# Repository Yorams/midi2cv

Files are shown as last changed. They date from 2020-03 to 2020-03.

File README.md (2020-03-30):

# midi2cv

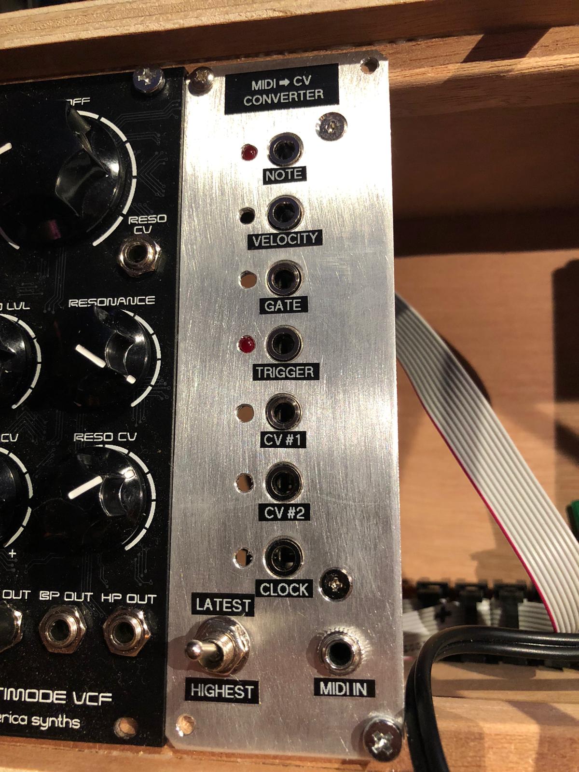
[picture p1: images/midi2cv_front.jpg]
midi2cv
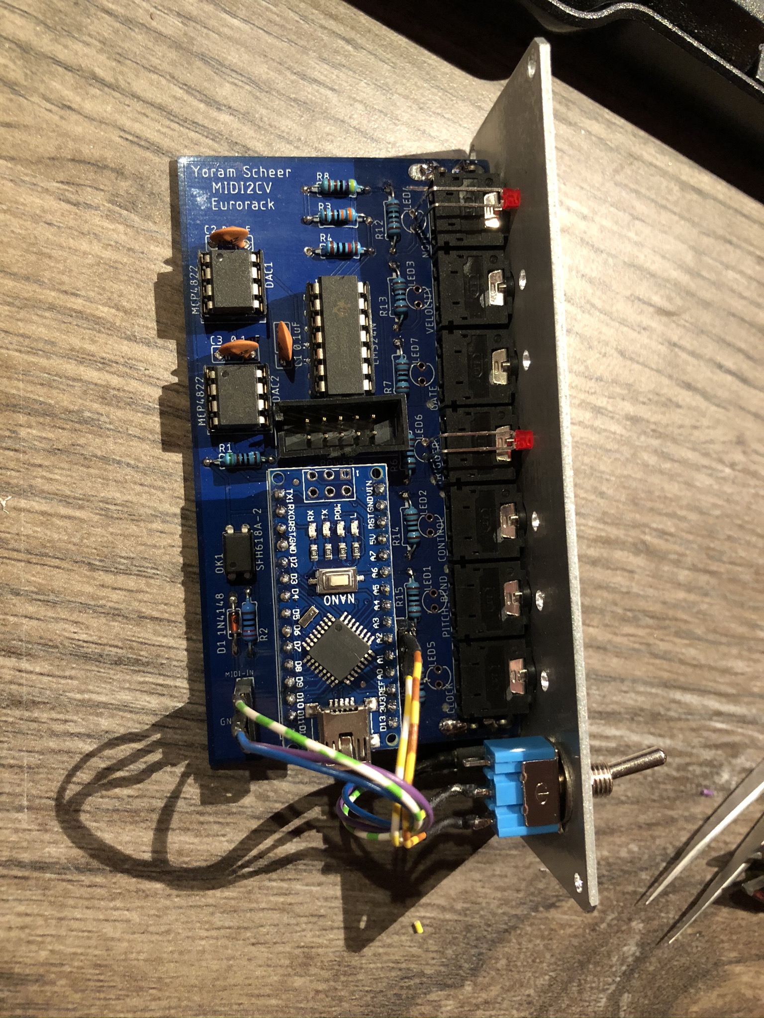
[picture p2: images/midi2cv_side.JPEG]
midi2cv
 

I forked this repository from elkayem, original found here: https://github.com/elkayem/midi2cv. I wanted to make an PCB from this schematic and needed to ajust a couple parts to match the right footprint on the PCB. 

The MIDI to CV converter includes the following outputs:

* Note CV output (88 keys, 1V/octave) using a 12-bit DAC
* Note priority (highest note, lowest note, or last note) selectable with jumper or 3-way switch
* Velocity CV output (0 to 4V)
* 2x Control Change CV outout (0 to 4V) (i changed the pitch bend to CC2 for 2 control channels)
* Trigger output (5V, 20 msec pulse for each new key played)
* Gate output (5V when any key depressed)
* Clock output (1 clock per quarter note, 20 msec 5V pulses)

## Parts
* Arduino Nano
* Optocoupler (I used a Vishay SFH618A, but there are plenty of alternatives out there)
* 2x MCP4822 12-bit DACs
* LM324N Quad Op Amp 
* Diode (e.g., 1N917)
* 220, 500, 3x1K, 7.7K (3K+4.7K), 10K Ohm resistors
* 3x 0.1 uF ceramic capacitors
* 3,5mm jack panel mount for MIDI over TRS
* 7x 3,5mm jack PCB mount Horizontal (farnell code: 2518188)
* 3-pin header and jumper *or* 3-way switch
* 3-pin header to connect MIDI-In

The Arduino code uses the standard MIDI and SPI libraries, which can be found in the Arduino Library Manager. 

The schematic is illustrated at the bottom of this page (Eagle file included).  Input power (VIN) is 9-12V.  This is required for the Note CV op amp, used for the 0-7.3V note output.  1% metal film resistors are recommended for the 7.7K and 10K resistors, for a constant op-amp gain that does not change with temperature.  Note that 7.7K is not a standard resistor value.  I used a 3K and a 4.7K resistor in series, which are much more common values.  If precise tuning is desired, a trim pot can be added *or* the constant NOTE_SF can be adjusted in the code.  I opted for the latter.

Note priority is selected using a jumper attached to the three-pin header labelled NP_SEL in the schematic.  This header connects to the Arduino pins A0 and A2, with the center pin attached to ground.  Alternatively, a 3-way switch can be attached to this header. 

The note priority options and jumper configuration are as follows:
* **Highest Note:** When multiple notes are sounded simultaneously, the highest note being held will be sounded.  When the highest note is released, the next highest note will be played, and so on.  Remove the NP_SEL jumper to select this configuration.
* **Lowest Note:** Analagous to highest note, except the lowest note being held will be sounded. Connect the NP_SEL jumper to the A0 pin and center pin (ground) to select this configuration. 
* **Last Note:** The most recent note played will be sounded.  When that note is released, the next most recent note still being held will be sounded.  Connect the NP_SEL jumper to the A2 pin and center pin (ground) to select this configuration. 

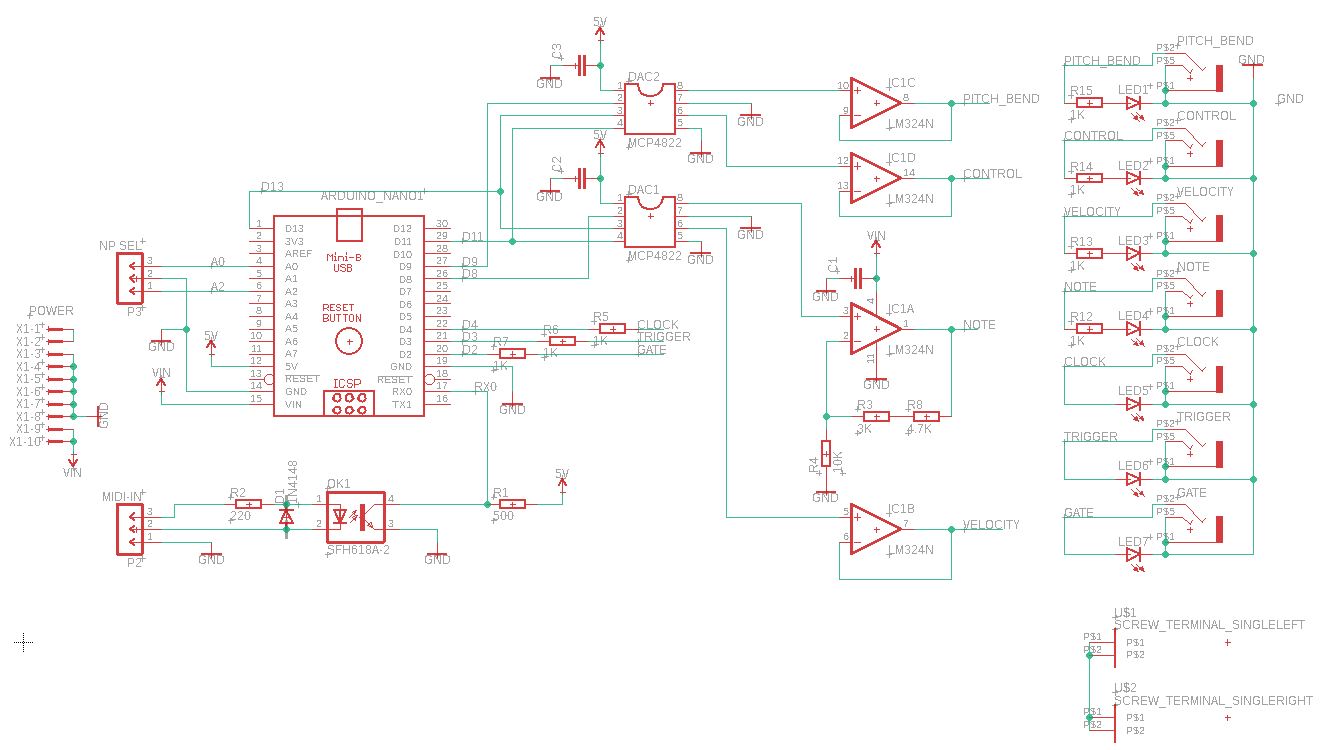
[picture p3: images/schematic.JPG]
schematic


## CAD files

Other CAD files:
frontpanel holes.dwg

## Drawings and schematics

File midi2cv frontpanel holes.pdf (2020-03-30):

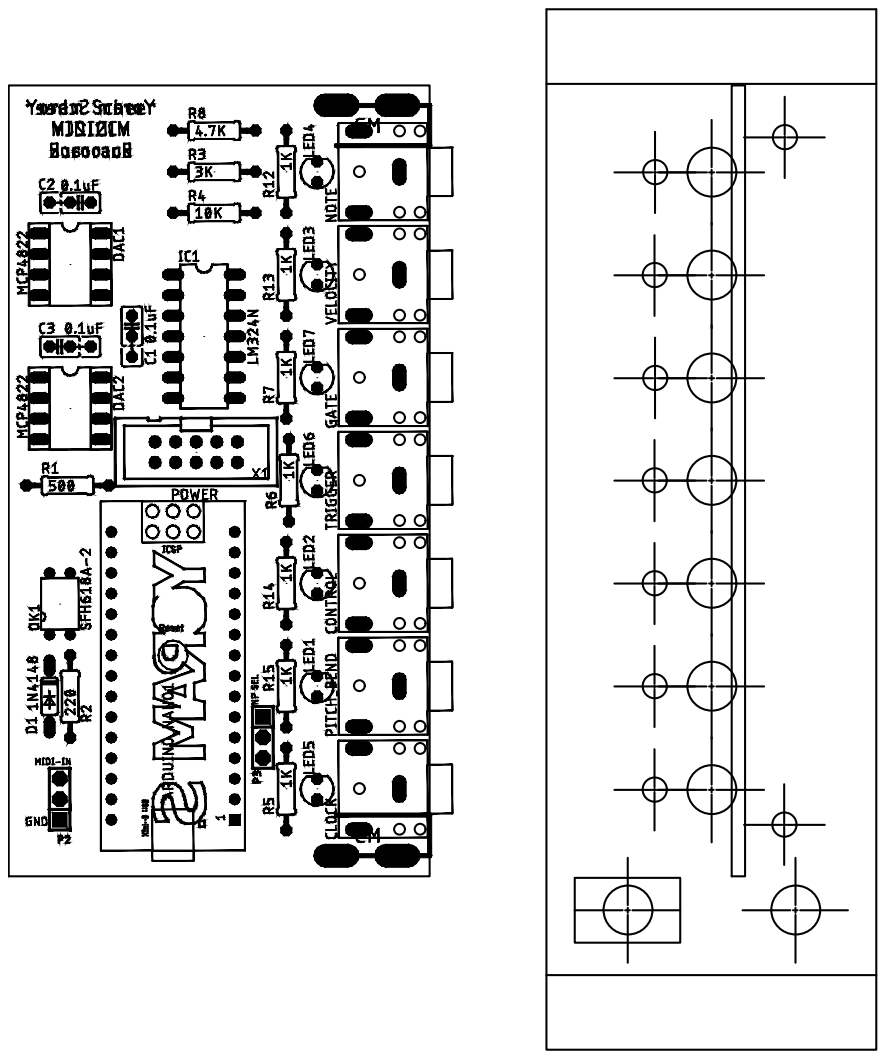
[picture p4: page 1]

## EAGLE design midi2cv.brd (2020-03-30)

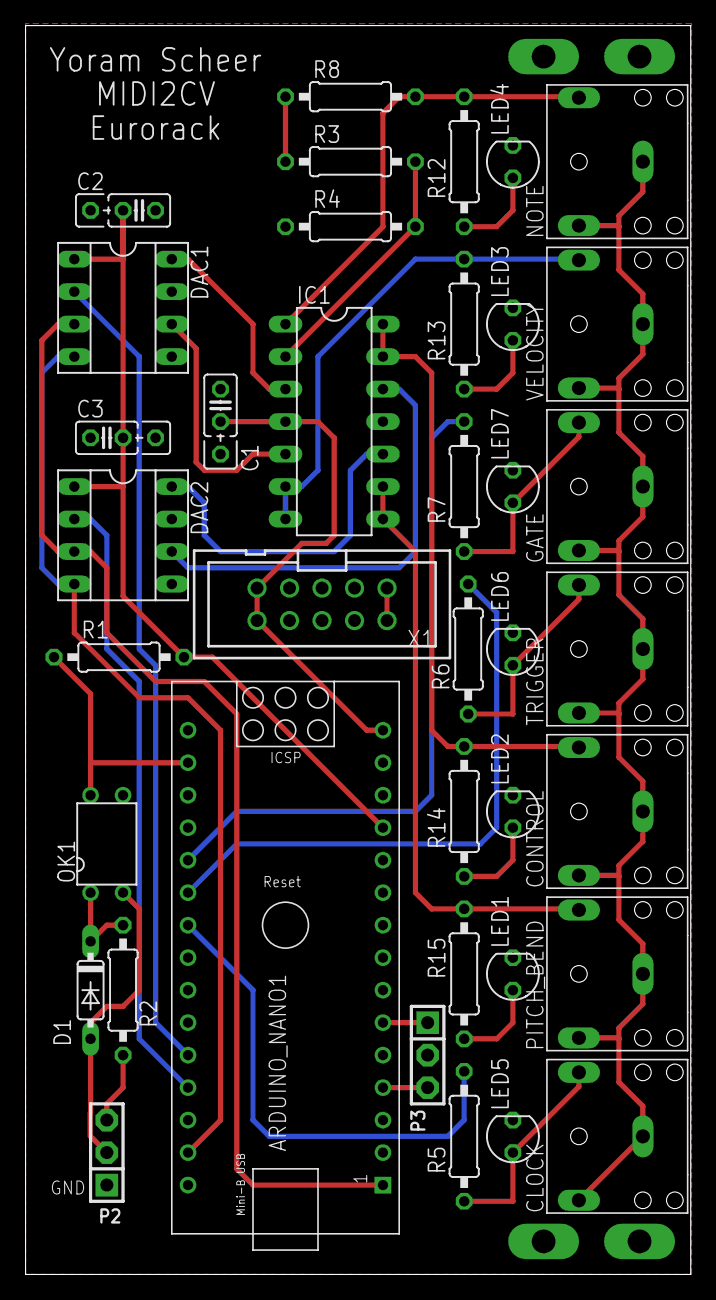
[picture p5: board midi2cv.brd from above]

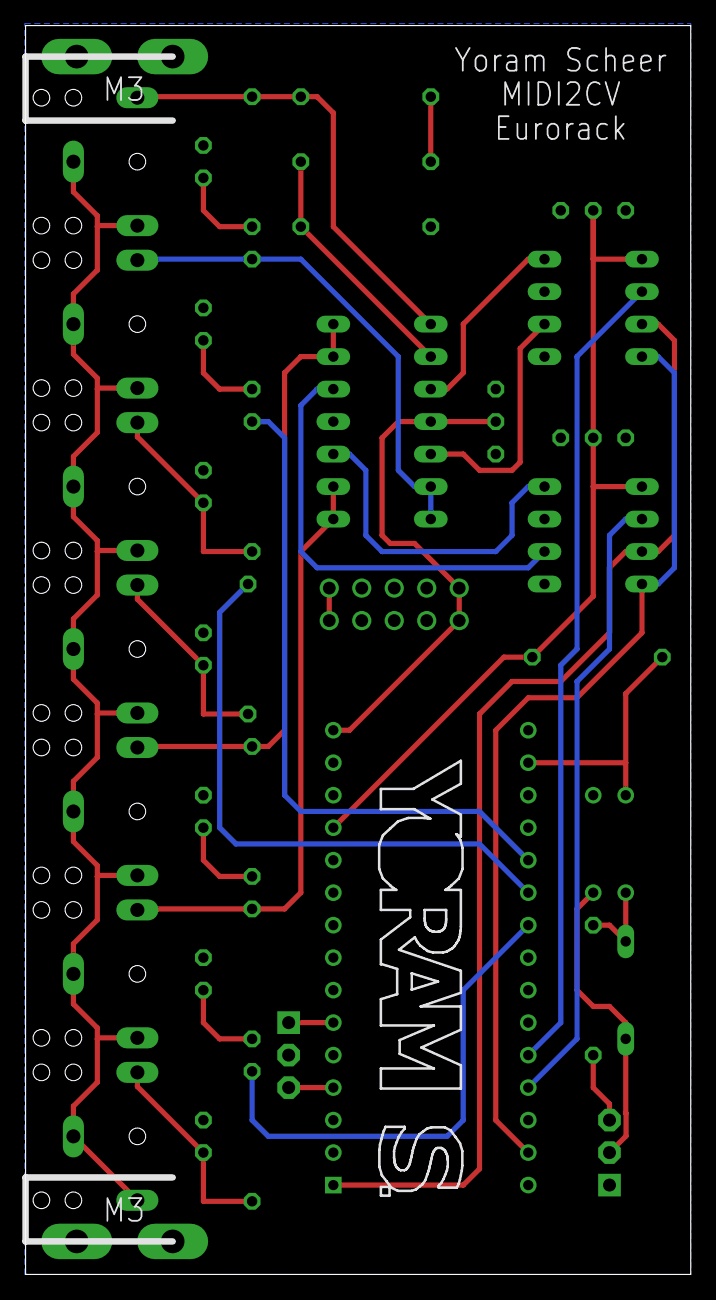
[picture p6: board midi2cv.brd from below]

Board: 2 copper layers, 52.0 x 97.6 mm, 41 parts (2 on the bottom side), 34 nets.

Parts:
ARDUINO_NANO1: ARDUINO_NANO
C1, C2, C3: 0.1uF; C025_050-025X075
CLOCK: 3.5_JACK_HORIZONTAL
CONTROL: 3.5_JACK_HORIZONTAL
D1: 1N4148; DO35-7
DAC1, DAC2: MCP4822; SOCKET-08
DRILEGEND: DRILEGEND
GATE: 3.5_JACK_HORIZONTAL
IC1: LM324N; DIL14
LED1, LED2, LED3, LED4, LED5, LED6, LED7: LED3MM
NOTE: 3.5_JACK_HORIZONTAL
OK1: SFH618A-2; DIP4
P2: MIDI-IN; SIP-100-03-40
P3: NP SEL; SIP-100-03-40
PITCH_BEND: 3.5_JACK_HORIZONTAL
R1: 500; 0207/10
R2: 220; 0207/10
R3: 3K; 0207/10
R4: 10K; 0207/10
R5, R6, R7, R12, R13, R14, R15: 1K; 0207/10
R8: 4.7K; 0207/10
TRIGGER: 3.5_JACK_HORIZONTAL
U$1: SCREW_TERMINAL_SINGLELEFT; SCREW_TERM_SINGLE_LEFT
U$2: SCREW_TERMINAL_SINGLERIGHT; SCREW_TERM_SINGLE_RIGHT
VELOCITY: 3.5_JACK_HORIZONTAL
X1: POWER; PAK100/2500-10

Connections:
5V: ARDUINO_NANO1.12, C2.2, C3.2, DAC1.1, DAC2.1, R1.2
A0: ARDUINO_NANO1.4, P3.3
A2: ARDUINO_NANO1.6, P3.1
CLOCK: CLOCK.P$2, LED5.A, R5.2
CONTROL: CONTROL.P$2, IC1.13, IC1.14, R14.1
D2: ARDUINO_NANO1.20, R7.1
D3: ARDUINO_NANO1.21, R6.1
D4: ARDUINO_NANO1.22, R5.1
D8: ARDUINO_NANO1.26, DAC1.2
D9: ARDUINO_NANO1.27, DAC2.2
D11: ARDUINO_NANO1.29, DAC1.4, DAC2.4
D13: ARDUINO_NANO1.1, DAC1.3, DAC2.3
GATE: GATE.P$2, LED7.A, R7.2
GND: ARDUINO_NANO1.14, ARDUINO_NANO1.19, C1.1, C2.1, C3.1, CLOCK.P$1, CLOCK.P$5, CONTROL.P$1, CONTROL.P$5, DAC1.5, DAC1.7, DAC2.5, DAC2.7, GATE.P$1, GATE.P$5, IC1.11, LED1.K, LED2.K, LED3.K, LED4.K, LED5.K, LED6.K, LED7.K, NOTE.P$1, NOTE.P$5, OK1.3, P2.1, P3.2, PITCH_BEND.P$1, PITCH_BEND.P$5, R4.1, TRIGGER.P$1, TRIGGER.P$5, U$1.P$1, U$1.P$2, U$2.P$1, U$2.P$2, VELOCITY.P$1, VELOCITY.P$5, X1.3, X1.4, X1.5, X1.6, X1.7, X1.8
unnamed: D1.C, OK1.1, R2.2
unnamed: D1.A, OK1.2, P2.2
unnamed: P2.3, R2.1
unnamed: DAC1.8, IC1.3
unnamed: R3.2, R8.1
unnamed: IC1.2, R3.1, R4.2
unnamed: DAC1.6, IC1.5
unnamed: DAC2.8, IC1.10
unnamed: DAC2.6, IC1.12
unnamed: X1.1, X1.2
unnamed: LED4.A, R12.2
unnamed: LED3.A, R13.2
unnamed: LED2.A, R14.2
unnamed: LED1.A, R15.2
NOTE: IC1.1, NOTE.P$2, R8.2, R12.1
PITCH_BEND: IC1.8, IC1.9, PITCH_BEND.P$2, R15.1
RX0: ARDUINO_NANO1.17, OK1.4, R1.1
TRIGGER: LED6.A, R6.2, TRIGGER.P$2
VELOCITY: IC1.6, IC1.7, R13.1, VELOCITY.P$2
VIN: ARDUINO_NANO1.15, C1.2, IC1.4, X1.9, X1.10

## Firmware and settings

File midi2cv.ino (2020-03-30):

/* 
 *    MIDI2CV 
 *    Copyright (C) 2017  Larry McGovern
 *  
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
 *    This program is distributed in the hope that it will be useful,
 *    but WITHOUT ANY WARRANTY; without even the implied warranty of
 *    MERCHANTABILITY or FITNESS FOR A PARTICULAR PURPOSE.  See the
 *    GNU General Public License <http://www.gnu.org/licenses/> for more details.
 */
 
#include <MIDI.h>
#include <SPI.h>

// Note priority is set by pins A0 and A2
// Highest note priority: A0 and A2 high (open)
// Lowest note priority:  A0 low (ground), A2 high (open)
// Last note priority:    A2 low (ground)
 
#define NP_SEL1 A0  // Note priority is set by pins A0 and A2
#define NP_SEL2 A2  

#define GATE  2
#define TRIG  3
#define CLOCK 4
#define DAC1  8 
#define DAC2  9

MIDI_CREATE_DEFAULT_INSTANCE();

void setup()
{
 pinMode(NP_SEL1, INPUT_PULLUP);
 pinMode(NP_SEL2, INPUT_PULLUP);
 
 pinMode(GATE, OUTPUT);
 pinMode(TRIG, OUTPUT);
 pinMode(CLOCK, OUTPUT);
 pinMode(DAC1, OUTPUT);
 pinMode(DAC2, OUTPUT);
 digitalWrite(GATE,LOW);
 digitalWrite(TRIG,LOW);
 digitalWrite(CLOCK,LOW);
 digitalWrite(DAC1,HIGH);
 digitalWrite(DAC2,HIGH);
 

 SPI.begin();

 MIDI.begin(MIDI_CHANNEL_OMNI);

 // Set initial pitch bend voltage to 0.5V (mid point).  With Gain = 1X, this is 1023
 // Other DAC outputs will come up as 0V, so don't need to be initialized
 setVoltage(DAC2, 0, 0, 1023);  
}

bool notes[88] = {0}; 
int8_t noteOrder[20] = {0}, orderIndx = {0};
unsigned long trigTimer = 0;

void loop()
{
  int type, noteMsg, velocity, channel, d1, d2;
  static unsigned long clock_timer=0, clock_timeout=0;
  static unsigned int clock_count=0;
  bool S1, S2;

  if ((trigTimer > 0) && (millis() - trigTimer > 20)) { 
    digitalWrite(TRIG,LOW); // Set trigger low after 20 msec 
    trigTimer = 0;  
  }

  if ((clock_timer > 0) && (millis() - clock_timer > 20)) { 
    digitalWrite(CLOCK,LOW); // Set clock pulse low after 20 msec 
    clock_timer = 0;  
  }
  
  if (MIDI.read()) {                    
    byte type = MIDI.getType();
    switch (type) {
      case midi::NoteOn: 
      case midi::NoteOff:
        noteMsg = MIDI.getData1() - 21; // A0 = 21, Top Note = 108
        channel = MIDI.getChannel();
        
        if ((noteMsg < 0) || (noteMsg > 87)) break; // Only 88 notes of keyboard are supported

        if (type == midi::NoteOn) velocity = MIDI.getData2();
        else velocity  = 0;  

        if (velocity == 0)  {
          notes[noteMsg] = false;
        }
        else {
          notes[noteMsg] = true;
          // velocity range from 0 to 4095 mV  Left shift d2 by 5 to scale from 0 to 4095, 
          // and choose gain = 2X
          setVoltage(DAC1, 1, 1, velocity<<5);  // DAC1, channel 1, gain = 2X
        }

        // Pins NP_SEL1 and NP_SEL2 indictate note priority
        S1 = digitalRead(NP_SEL1);
        S2 = digitalRead(NP_SEL2);

        if (S1 && S2) { // Highest note priority
          commandTopNote();
        }
        else if (!S1 && S2) { // Lowest note priority
          commandBottomNote();
        }
        else { // Last note priority
           if (notes[noteMsg]) {  // If note is on and using last note priority, add to ordered list
            orderIndx = (orderIndx+1) % 20;
            noteOrder[orderIndx] = noteMsg;                 
          }
          commandLastNote();         
        }
        break;
        
      case midi::PitchBend:
        d1 = MIDI.getData1();
        d2 = MIDI.getData2(); // d2 from 0 to 127, mid point = 64

        // Pitch bend output from 0 to 1023 mV.  Left shift d2 by 4 to scale from 0 to 2047.
        // With DAC gain = 1X, this will yield a range from 0 to 1023 mV.  
        //setVoltage(DAC2, 0, 0, d2<<4);  // DAC2, channel 0, gain = 1X
        
        break;

      case midi::ControlChange: 
        d1 = MIDI.getData1();
        d2 = MIDI.getData2(); // From 0 to 127

        // CC range from 0 to 4095 mV  Left shift d2 by 5 to scale from 0 to 4095, 
        // and choose gain = 2X
        
        if(d1 == 1){
          setVoltage(DAC2, 1, 1, d2<<5);  // DAC2, channel 1, gain = 2X
        }
        if(d1 == 2){
          setVoltage(DAC2, 0, 1, d2<<5);  // DAC2, channel 0, gain = 1X
        }
        
        break;
        
      case midi::Clock:
        if (millis() > clock_timeout + 300) clock_count = 0; // Prevents Clock from starting in between quarter notes after clock is restarted!
        clock_timeout = millis();
        
        if (clock_count == 0) {
          digitalWrite(CLOCK,HIGH); // Start clock pulse
          clock_timer=millis();    
        }
        clock_count++;
        if (clock_count == 24) {  // MIDI timing clock sends 24 pulses per quarter note.  Sent pulse only once every 24 pulses
          clock_count = 0;  
        }
        break;
        
      case midi::ActiveSensing: 
        break;
        
      default:
        d1 = MIDI.getData1();
        d2 = MIDI.getData2();
    }
  }
}

void commandTopNote()
{
  int topNote = 0;
  bool noteActive = false;
  
  for (int i=0; i<88; i++)
  {
    if (notes[i]) {
      topNote = i;
      noteActive = true;
    }
  }

  if (noteActive) 
    commandNote(topNote);
  else // All notes are off, turn off gate
    digitalWrite(GATE,LOW);  
}

void commandBottomNote()
{
  int bottomNote = 0;
  bool noteActive = false;
 
  for (int i=87; i>=0; i--)
  {
    if (notes[i]) {
      bottomNote = i;
      noteActive = true;
    }
  }

  if (noteActive) 
    commandNote(bottomNote);
  else // All notes are off, turn off gate
    digitalWrite(GATE,LOW);
}

void commandLastNote()
{

  int8_t noteIndx;
  
  for (int i=0; i<20; i++) {
    noteIndx = noteOrder[ mod(orderIndx-i, 20) ];
    if (notes[noteIndx]) {
      commandNote(noteIndx);
      return;
    }
  }
  digitalWrite(GATE,LOW);  // All notes are off
}

// Rescale 88 notes to 4096 mV:
//    noteMsg = 0 -> 0 mV 
//    noteMsg = 87 -> 4096 mV
// DAC output will be (4095/87) = 47.069 mV per note, and 564.9655 mV per octive
// Note that DAC output will need to be amplified by 1.77X for the standard 1V/octave 

#define NOTE_SF 47.069f // This value can be tuned if CV output isn't exactly 1V/octave

void commandNote(int noteMsg) {
  digitalWrite(GATE,HIGH);
  digitalWrite(TRIG,HIGH);
  trigTimer = millis();
  
  unsigned int mV = (unsigned int) ((float) noteMsg * NOTE_SF + 0.5); 
  setVoltage(DAC1, 0, 1, mV);  // DAC1, channel 0, gain = 2X
}

// setVoltage -- Set DAC voltage output
// dacpin: chip select pin for DAC.  Note and velocity on DAC1, pitch bend and CC on DAC2
// channel: 0 (A) or 1 (B).  Note and pitch bend on 0, velocity and CC on 2.
// gain: 0 = 1X, 1 = 2X.  
// mV: integer 0 to 4095.  If gain is 1X, mV is in units of half mV (i.e., 0 to 2048 mV).
// If gain is 2X, mV is in units of mV

void setVoltage(int dacpin, bool channel, bool gain, unsigned int mV)
{
  unsigned int command = channel ? 0x9000 : 0x1000;

  command |= gain ? 0x0000 : 0x2000;
  command |= (mV & 0x0FFF);
  
  SPI.beginTransaction(SPISettings(8000000, MSBFIRST, SPI_MODE0));
  digitalWrite(dacpin,LOW);
  SPI.transfer(command>>8);
  SPI.transfer(command&0xFF);
  digitalWrite(dacpin,HIGH);
  SPI.endTransaction();
}

int mod(int a, int b)
{
    int r = a % b;
    return r < 0 ? r + b : r;
}

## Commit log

2020-03-30 Changed parts for PCB
    Changed a couple of parts for the PCB design.
    [midi2cv.sch]
2020-03-30 Added PCB design
    [midi2cv v1.2.brd]
2020-03-30 Changed filename to match .sch
    [midi2cv.brd]
2020-03-30 Changed the pitch bend to CC2

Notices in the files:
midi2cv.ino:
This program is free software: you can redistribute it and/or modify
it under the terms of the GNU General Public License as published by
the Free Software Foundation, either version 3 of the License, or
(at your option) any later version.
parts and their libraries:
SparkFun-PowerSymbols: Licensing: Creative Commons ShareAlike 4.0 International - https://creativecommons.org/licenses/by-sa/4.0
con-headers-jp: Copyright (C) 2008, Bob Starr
